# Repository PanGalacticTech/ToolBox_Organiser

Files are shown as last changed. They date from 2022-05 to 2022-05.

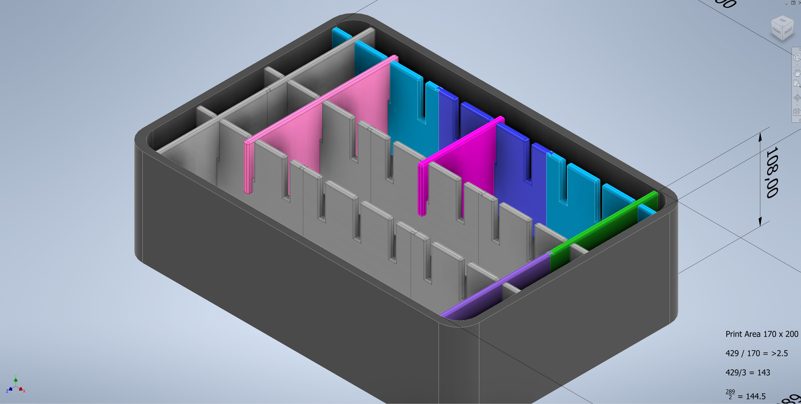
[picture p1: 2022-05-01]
Media/False Colour parts.png

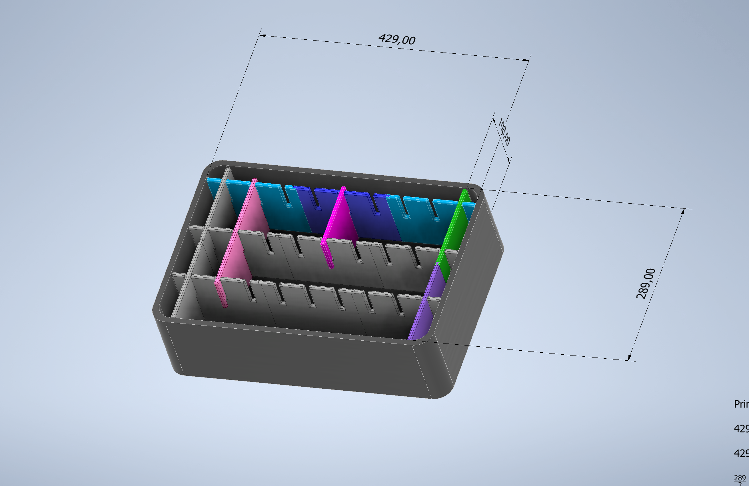
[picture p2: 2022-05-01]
Media/toolBox.png

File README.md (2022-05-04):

# ToolBox_Organiser
 STL and .ipt files for Peli Style Toolcase Organiser

I have been trying to find a cheap but smart solution for organising my tools in my Peli Style toolcase.

I found a few off the shelf versions, I particularly liked this product from [TrekPak](https://www.waterproof-cases.co.uk/product/trekpak-1510-for-peli-1510-case).

However the cost was extremly offputting given the materials they used. I wanted something clean and configurable but cheaper. Preferably with materials I already had to hand.

## My Solution: 3D Printed ToolCase Inserts


The inserts are made up of a total of 6 different parts. The minimum parts to make the inserts are:

| Quantity | Part | Colour |
|--- |--- |--- |
| 4 x | Part A | Light Blue |
| 2 x | Part B | Dark Blue |
| 2 x | Part C | Green |
| 2 x | Part D | Purple |
|  10 | Parts Total | |

Part B is glued between 2 x part A to make up one of the horizontal dividers. <br>

Part C and Part D are glued together to make up one vertical dividers. <br>

Additional horizontal and vertical dividors can be printed as required. <br>

Part E and F (Pink) are shorter row dividers and can be printed as required to splitting up rows into shorter sections.

This was done to make sure the parts could be printed on smaller printers. I dont think any part is larger than 150mmx150mm  <br>

All parts are 7mm wide, and so far seem strong enough to work for this purpose.

<br><br>
Find all finished STLs in V1.0 Parts folder

## Print Settings

I am using an AnyCubic S3, and I have chosen to print each part standing up. With my current print settings in cura:
| Setting | Value |
|--- |--- |
|Layer Height | 0.2 mm |
|Print Speed  | 50mm/s |
|Infill | 18.0% |
|Infill Pattern | Gyroid |
|Build Plate | Brim |
|Brim Width | 8.0 mm |

The average parts are coming out as just under 5 hours of print time, and uses approximatly 50g of PLA.

Total print time for my use will be ~ 65 hours!

## Costing and Materials

Using the settings above, I would expect the minimum frame to use just over 500g of material, therefore it will use about half a roll of PLA, and cost me about £12.50
in raw material costs. Even with an additional long divider and a couple of the shorter dividers, the whole lots shouldnt cost more than a single reel of PLA, making it much cheaper than the off the shelf alternative I found earlier.

## Box Inner Dimensions

ISOmetric view showing inner box dimensions.
Dimensions

Closer look at the structure of the dividers.


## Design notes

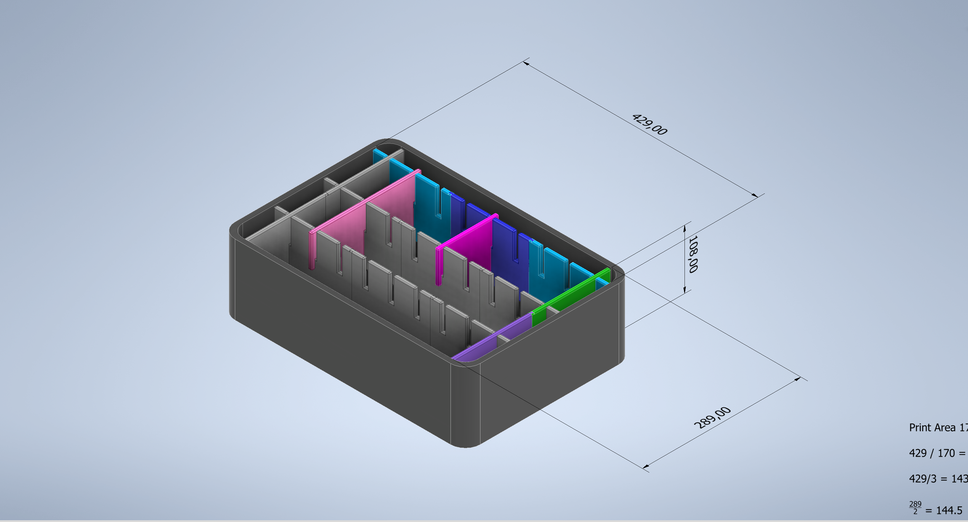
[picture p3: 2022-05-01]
Media/Dimensions.png

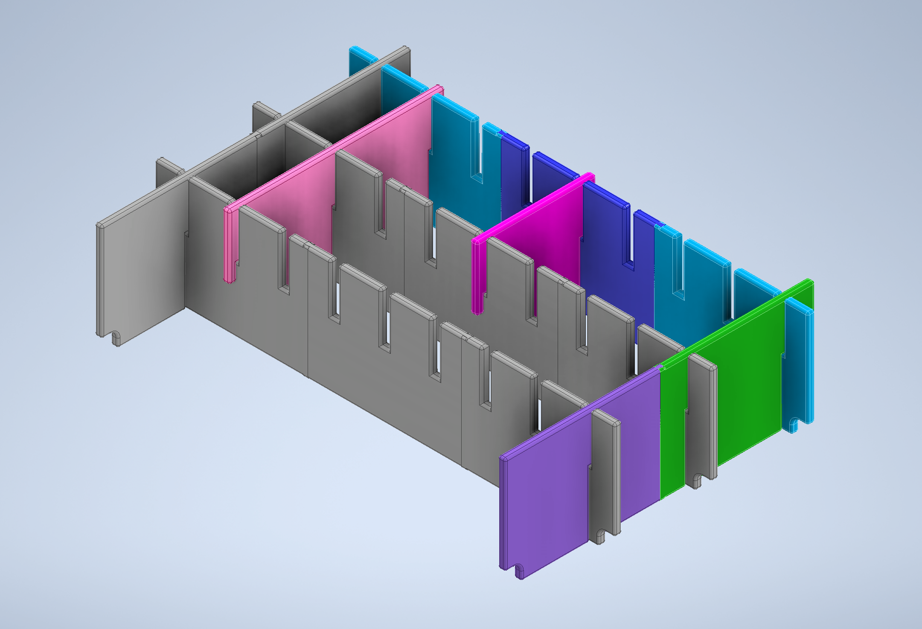
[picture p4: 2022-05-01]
Media/toolbox_organiser.png

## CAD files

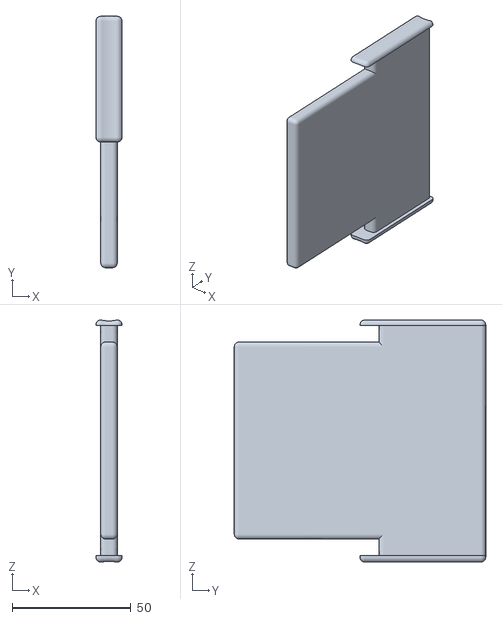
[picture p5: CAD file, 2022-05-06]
V1.2 Parts/PART_E_Single_div.stl
11.0 x 106.0 x 102.0

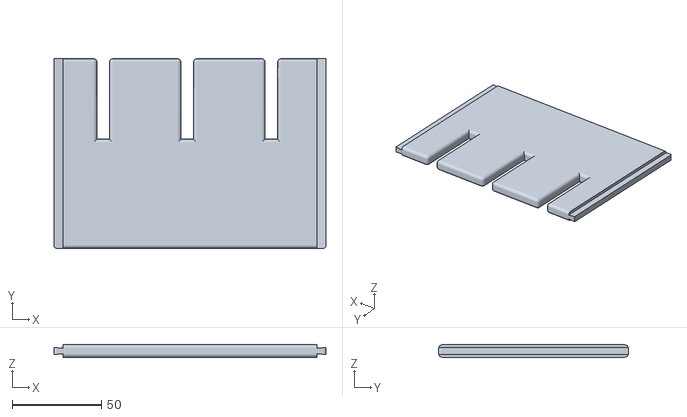
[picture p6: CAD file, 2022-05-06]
V1.2 Parts/PART_B_hoz_V1.2.stl
152.0 x 106.0 x 7.00

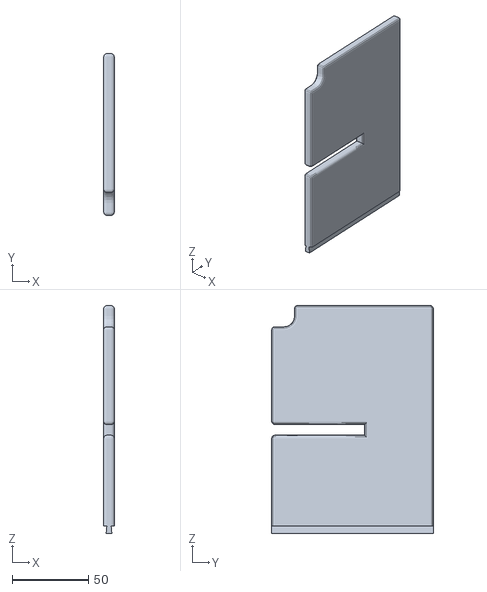
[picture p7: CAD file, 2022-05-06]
V1.2 Parts/PART_D_vert_V1.2.stl
7.00 x 106.0 x 149.4

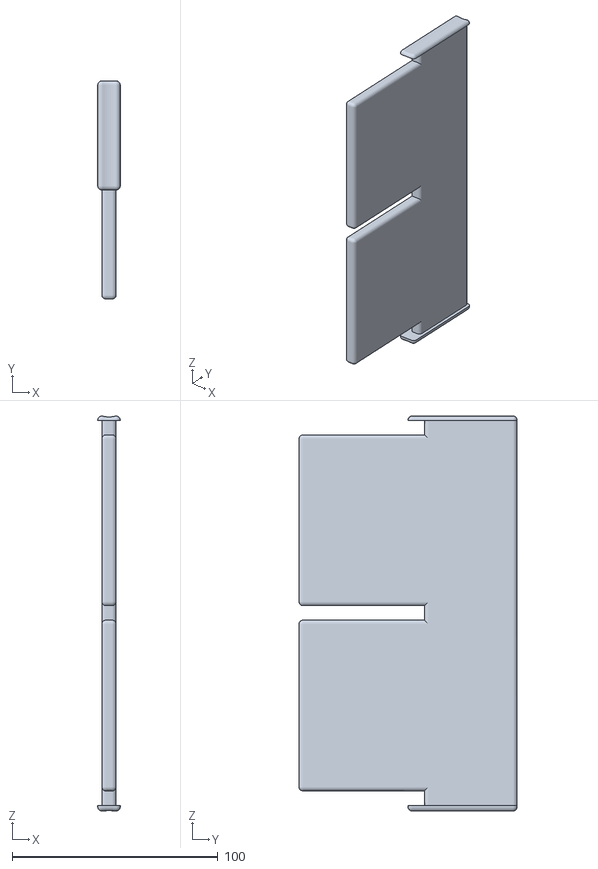
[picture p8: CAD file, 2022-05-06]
V1.2 Parts/PART_F_Dual_div.stl
11.0 x 106.0 x 191.9

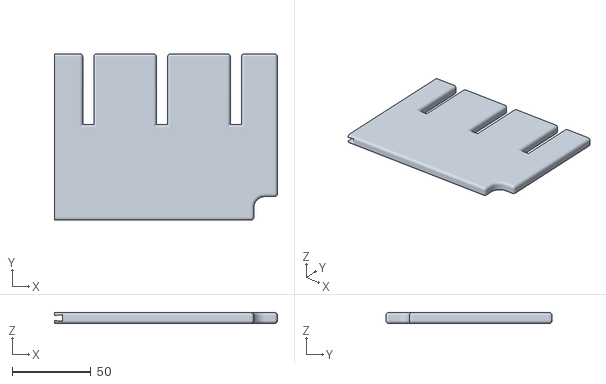
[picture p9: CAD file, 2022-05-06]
V1.2 Parts/PART_A_hoz_V1.2.stl
142.0 x 106.0 x 7.00

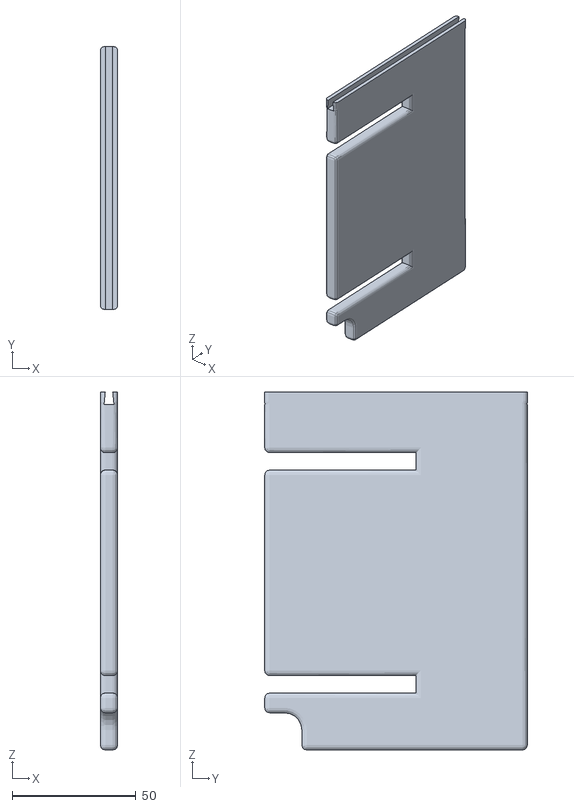
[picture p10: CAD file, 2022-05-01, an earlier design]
V1.0 Parts/PART_C_vert.stl
7.00 x 106.0 x 144.5

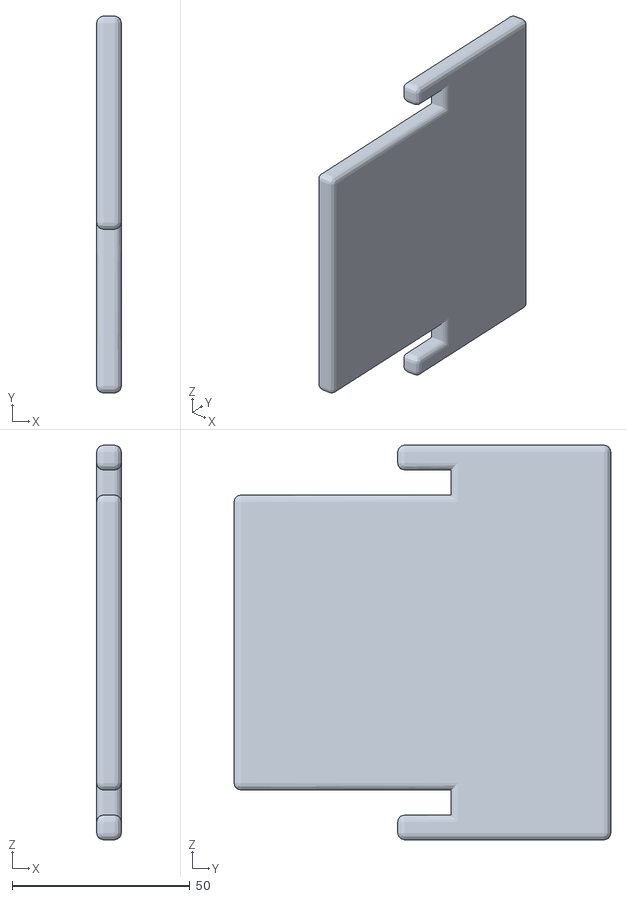
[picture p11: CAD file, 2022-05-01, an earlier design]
V1.0 Parts/PART_E_div.stl
7.00 x 106.0 x 111.0

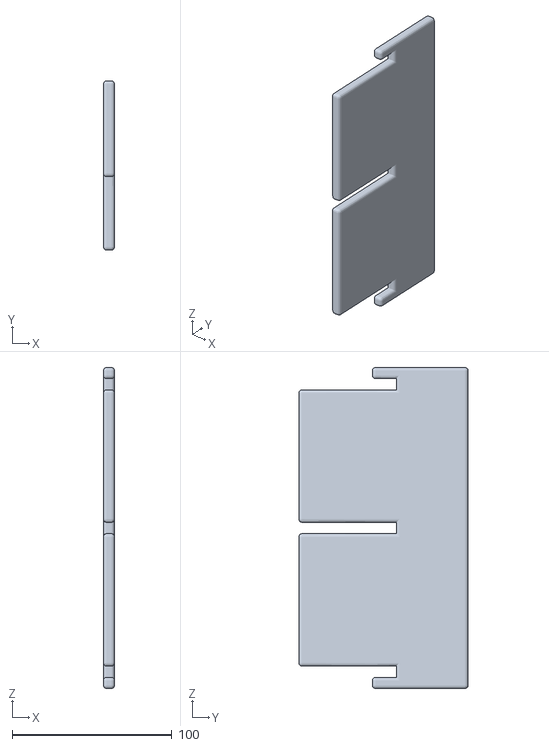
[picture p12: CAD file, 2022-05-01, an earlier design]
V1.0 Parts/PART_F_dual_div.stl
7.00 x 106.0 x 201.0

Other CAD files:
V1.2 Parts/PART_C_Vert_V1.2.stl
V1.1 Parts/PART_A_hoz_1.1.stl
V1.0 Parts/PART_A_hoz.stl
V1.0 Parts/PART_B_hoz.stl
V1.0 Parts/PART_D_vert.stl
OldVersions/ToolBox_Assembly.0008.ipt
OldVersions/Tray1_A.0021.ipt
PART_A_hoz.ipt
PART_A_hoz_1.1.ipt
PART_A_hoz_V1.2.ipt
PART_B_hoz.ipt
PART_C_Vert_V1.2.ipt
PART_C_vert.ipt
PART_D_vert.ipt
PART_D_vert_V1.2.ipt
PART_E_div.ipt
PART_F_2wayDiv.ipt
ToolBox_Assembly.ipt
Tray1_A.ipt

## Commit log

2022-05-01 updated filenames
    [PART_C_vert.ipt, Part1.ipt, Part2.ipt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]
2022-05-04 Made cutout on part_A larger to make assembly easier
    Probably need to make Part_B keyway smaller as well, but test first.
    If successful then part C and/or D will need the same keyway edit.
    Made all keyway sketches defined to themselves rather than features of the last one
    [PART_A_hoz_1.1.ipt, PART_A_hoz_1.1.stl, ToolBox_Assembly.ipt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]
2022-05-04 Adjusted centre dividers
    [ToolBox_Assembly.0003.ipt, ToolBox_Assembly.ipt]
2022-05-04 added print settings file
2022-05-05 adjusted part sizes
    [PART_C_Vert_V1.2.ipt, PART_C_Vert_V1.2.stl, ToolBox_Assembly.0003.ipt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]
2022-05-06 made parts smaller
    [PART_A_hoz_V1.2.ipt, PART_A_hoz_V1.2.stl, PART_B_hoz_V1.2.stl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]
